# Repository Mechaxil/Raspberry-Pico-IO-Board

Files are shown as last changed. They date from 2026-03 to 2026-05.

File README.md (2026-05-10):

# Mechaxil Pico IO Board - [Documentation website](https://docs.mechaxil.com/docs/products/pico-io-board)

A clean, minimal Raspberry Pi Pico-compatible breakout board designed for easy access to all GPIO pins.

<p align="center">
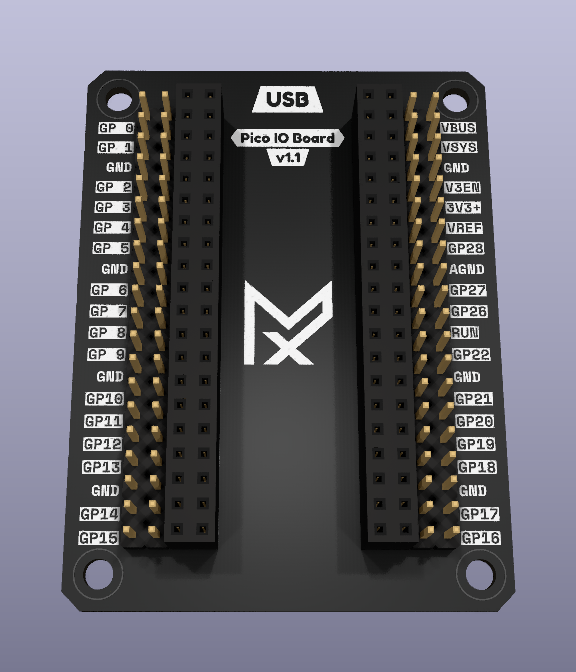
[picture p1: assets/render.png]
Render
  
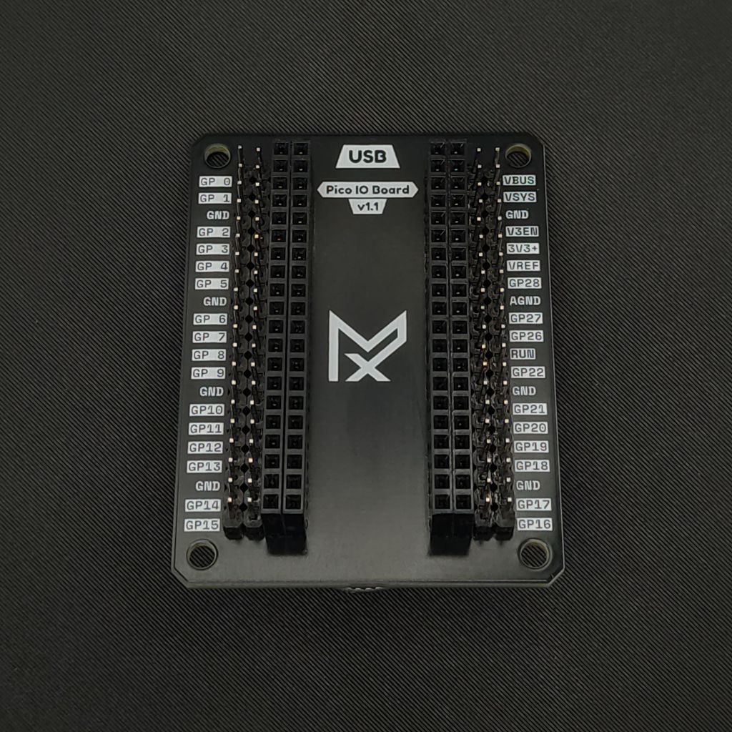
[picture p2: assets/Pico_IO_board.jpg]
Real
  
</p>

## Overview

The Mechaxil Pico IO Board expands the Raspberry Pi Pico pins so it's easier to use for prototyping.

Designed with usability, readability, and clean aesthetics in mind.

Perfect for prototyping, education, embedded development, and quick testing setups.

This board is available for purchase via the Mechaxil webshop:
[Mechaxil Webshop](https://mechaxil.com/products/pico-io-board)

## Features

- Full GPIO breakout  
- Clearly labeled pinout on silkscreen  
- Single-row female header  
- Dual-row male headers  
- Clean minimal design  

## Use Cases

- Rapid prototyping  
- Educational electronics kits  
- Embedded system development  
- DIY projects  

## Hardware

- Compatible with Raspberry Pi Pico and Pico-compatible boards  
- Standard 2.54 mm header spacing  
- Compact form factor  

## OSHW & License

As of 2026 May 8th this project was certified by OSHWA
<p align="center">
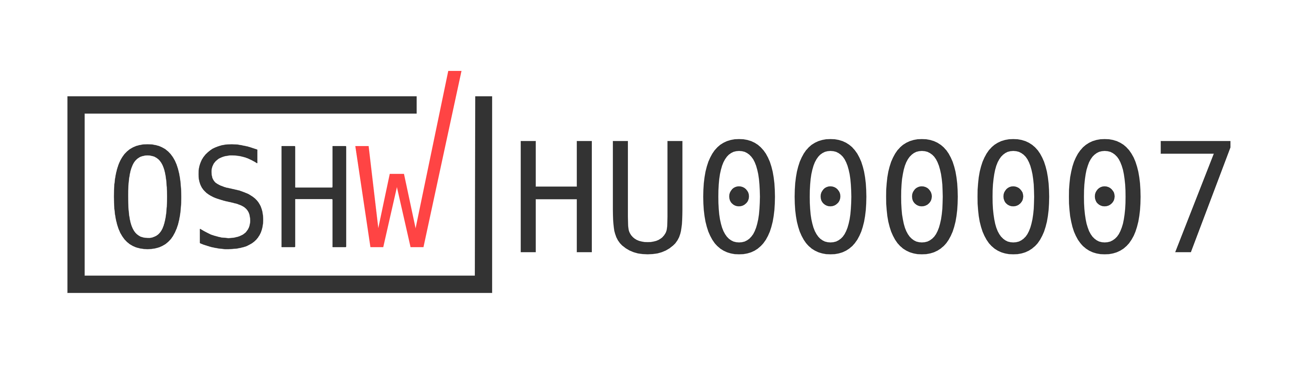
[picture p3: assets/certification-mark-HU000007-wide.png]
OSHW Mark
  
</p>

This project is licensed under the CERN Open Hardware Licence Version 2 - Weakly Reciprocal (CERN-OHL-W).

You are free to use, modify, manufacture, and sell.

Condition:
- Any modifications to the design must also be shared under the same license  

> [!IMPORTANT]
>
> ## Trademark & Branding Notice
>
> "Mechaxil" and the Mechaxil logo are trademarks of Mechaxil (Závoczki Attila e.v.).
> This license does not grant permission to use the Mechaxil name, logo, or branding for commercial or promotional purposes without prior written permission.
>
> If you manufacture, distribute, or sell this design (modified or unmodified):
>
> * You must remove the Mechaxil logo
> * You must remove any "Approved by Mechaxil" markings
> * You must not imply that your product is an official Mechaxil product
> * You must clearly state: "Original design by Mechaxil"
>
> This ensures transparency and avoids confusion between official Mechaxil products and third-party derivatives.

> [!IMPORTANT]
> ## Raspberry Pi Disclaimer
> "Raspberry Pi" is a trademark of the Raspberry Pi Foundation.
> This project is not affiliated with, endorsed by, or sponsored by the Raspberry Pi Foundation or Raspberry Pi Ltd.
> The term is used only for compatibility reference.

## Open Hardware

All design files are provided as schematics, PCB layouts, and production files.

Feel free to build, sell, improve, and share.

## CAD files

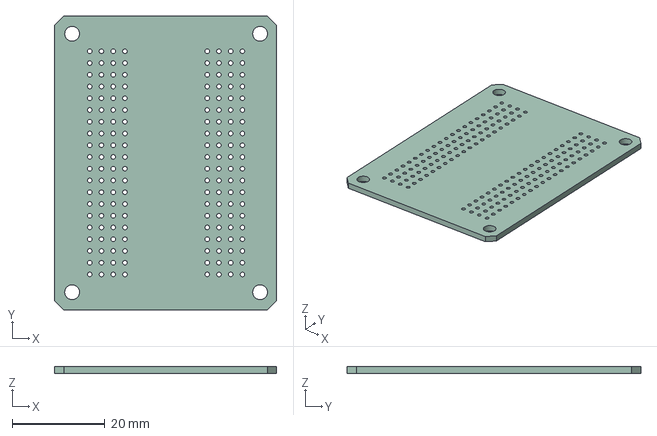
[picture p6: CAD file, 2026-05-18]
documentation/CAD/pico_io_board-no_component.step
48.0 x 63.5 x 1.51 mm

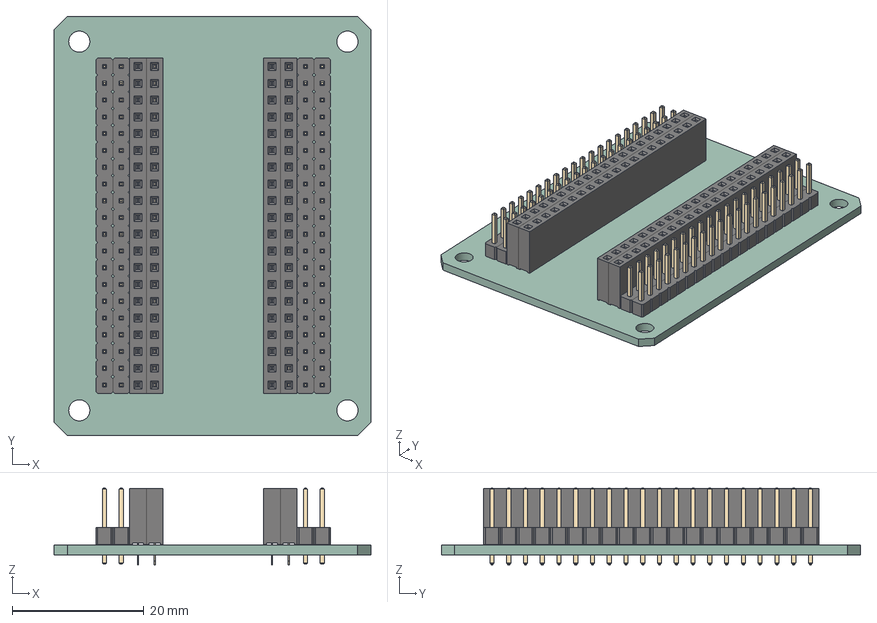
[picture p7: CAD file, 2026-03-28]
Raspberry_Pico_Breakout.step
48.0 x 63.5 x 11.6 mm
PinSocket_1x20_P2.54mm_Vertical x 4
PinHeader_1x20_P2.54mm_Vertical x 4
Raspberry_Pico_Breakout_PCB

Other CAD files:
documentation/CAD/pico_io_board-no_silkscreen.step

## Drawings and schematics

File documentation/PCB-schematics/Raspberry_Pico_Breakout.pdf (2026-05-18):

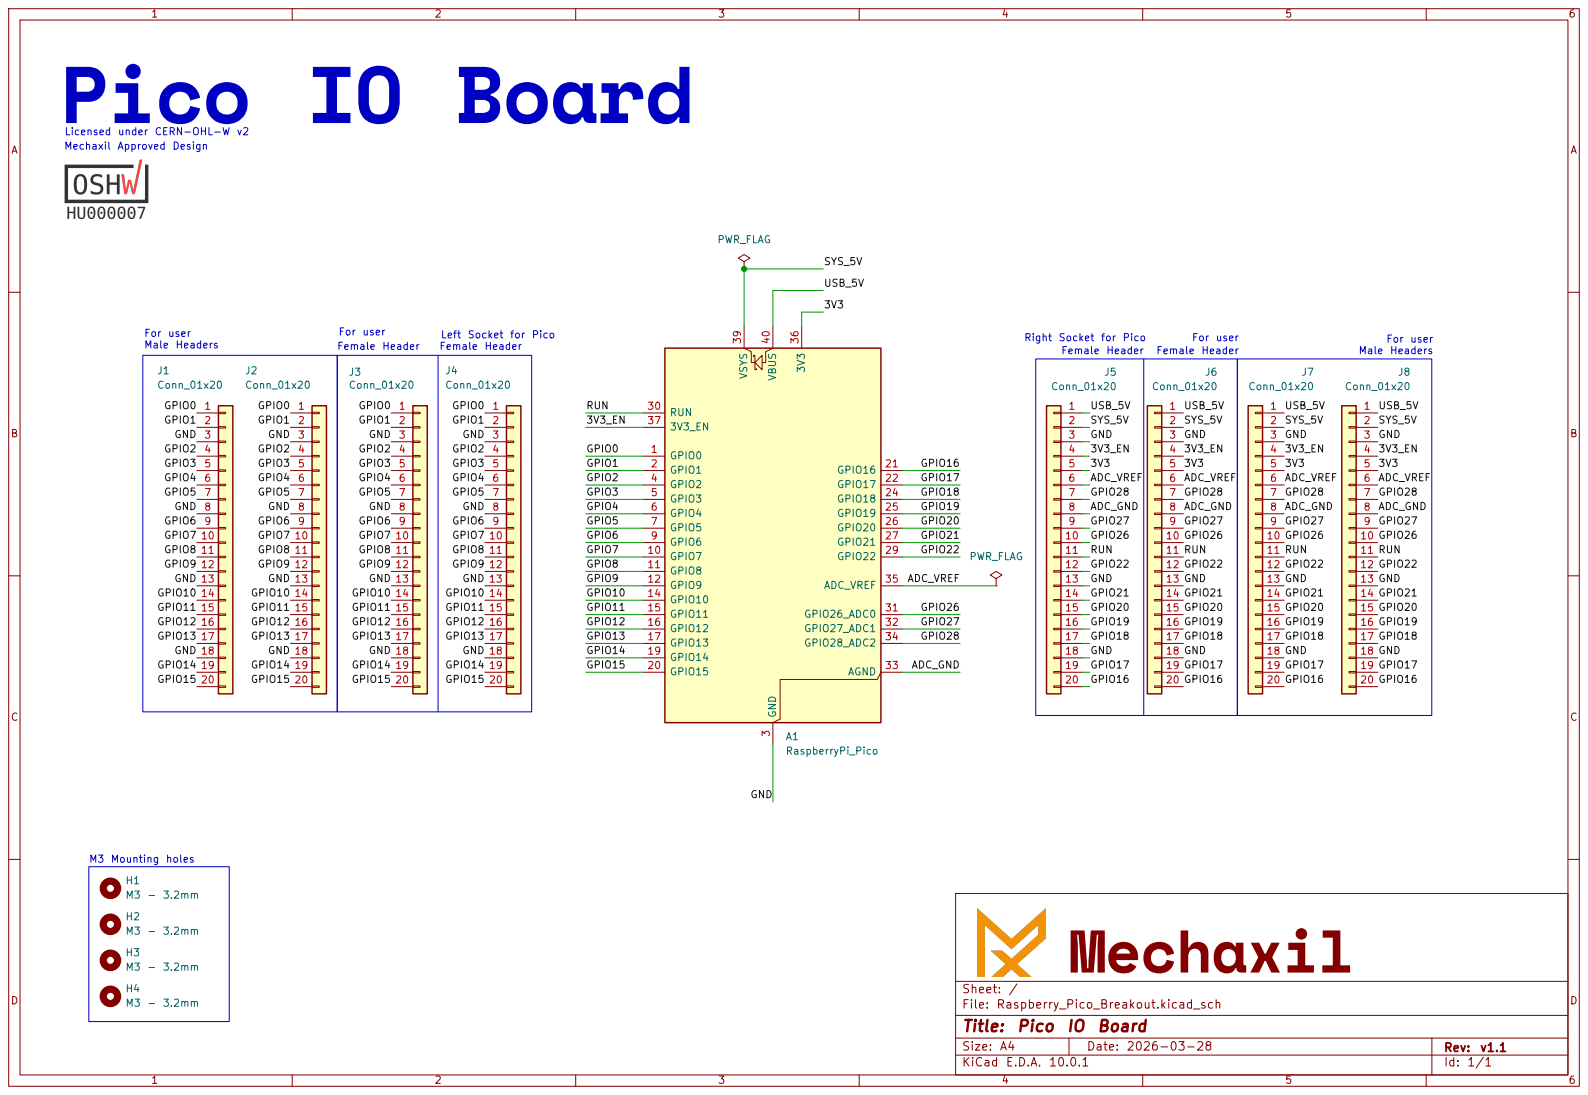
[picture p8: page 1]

Left Socket for Pico M3 Mounting holes

Sheet: /
File: Raspberry_Pico_Breakout.kicad_sch
Title: Pico IO Board

Size: A4 | Rev: v1.1
KiCad E.D.A. 10.0.1 | Id: 1/1

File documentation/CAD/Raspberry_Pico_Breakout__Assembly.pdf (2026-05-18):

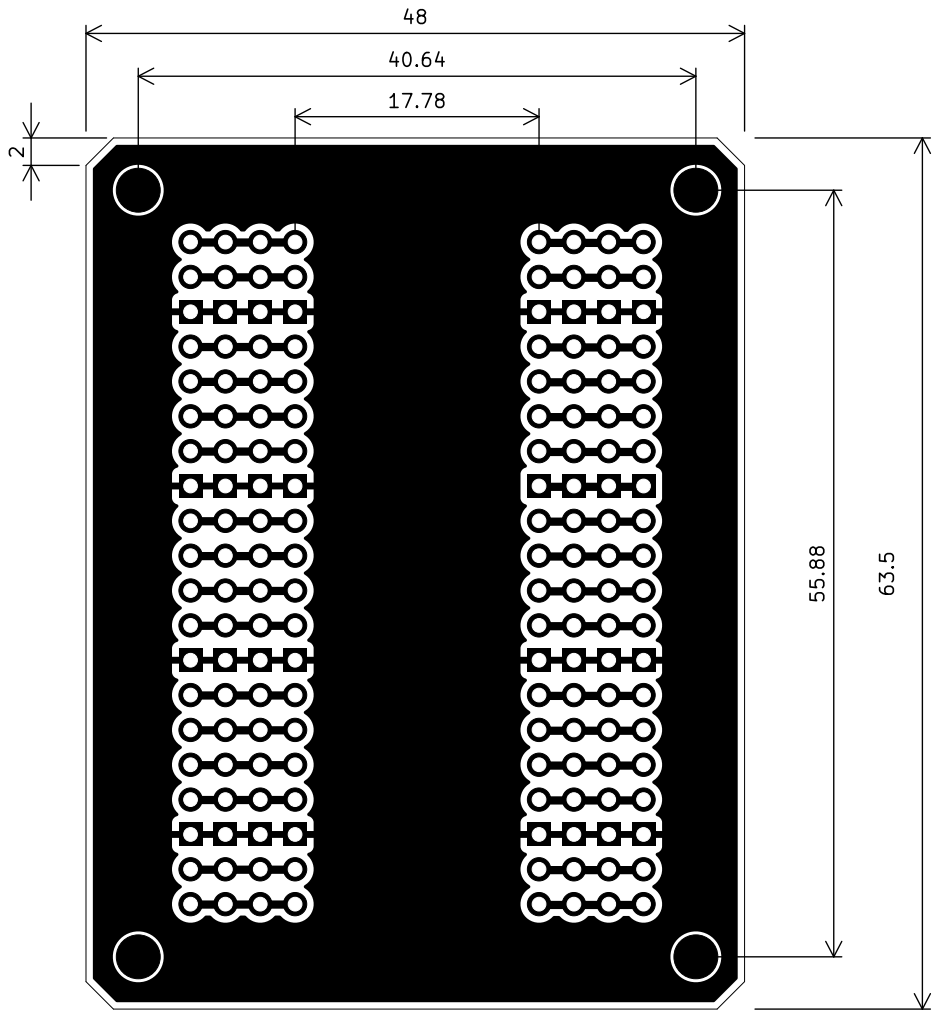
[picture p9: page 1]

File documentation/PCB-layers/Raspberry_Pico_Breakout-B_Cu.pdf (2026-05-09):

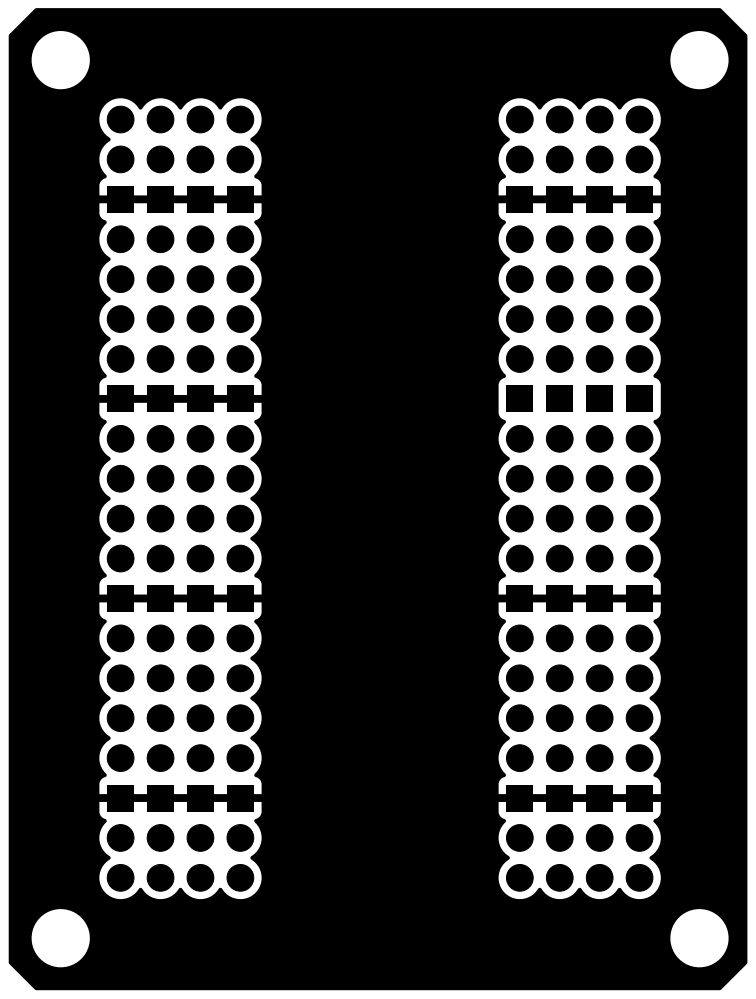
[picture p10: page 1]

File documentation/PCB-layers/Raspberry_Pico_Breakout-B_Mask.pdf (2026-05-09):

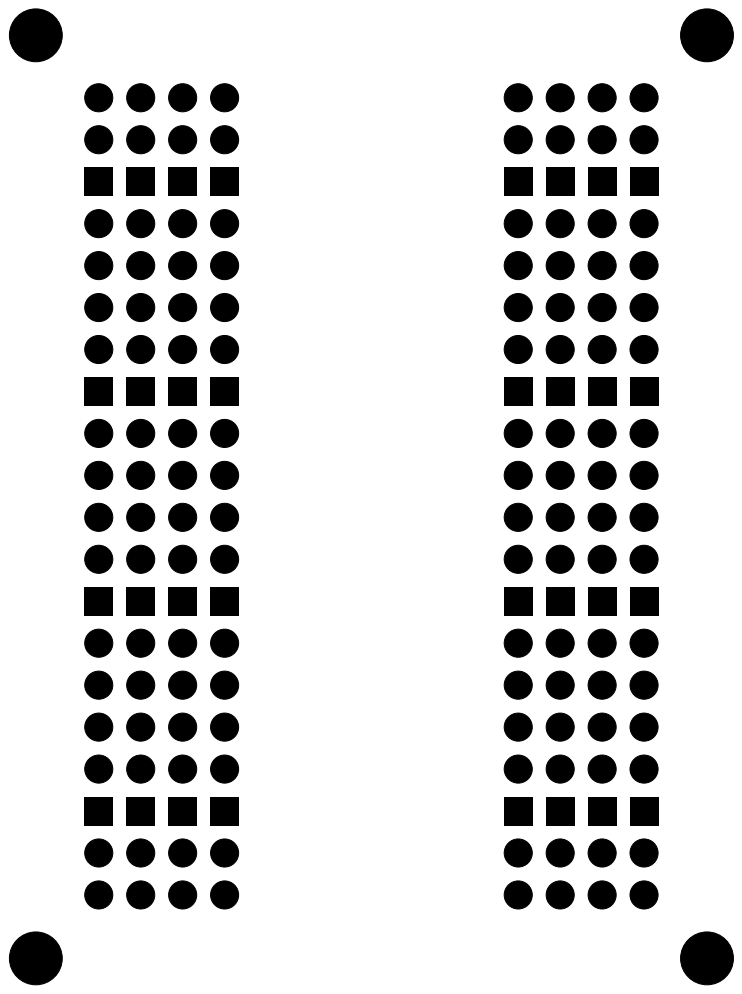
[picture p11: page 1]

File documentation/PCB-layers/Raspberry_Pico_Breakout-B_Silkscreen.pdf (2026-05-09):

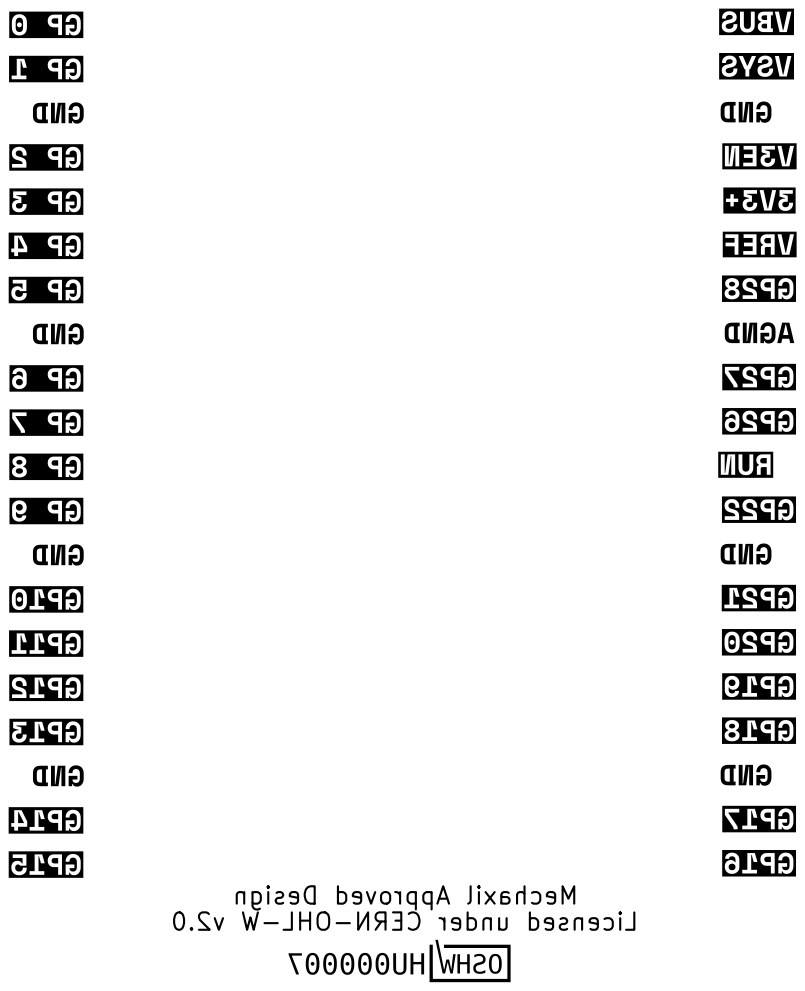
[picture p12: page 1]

v2.0 CERN-OHL-W under Licensed

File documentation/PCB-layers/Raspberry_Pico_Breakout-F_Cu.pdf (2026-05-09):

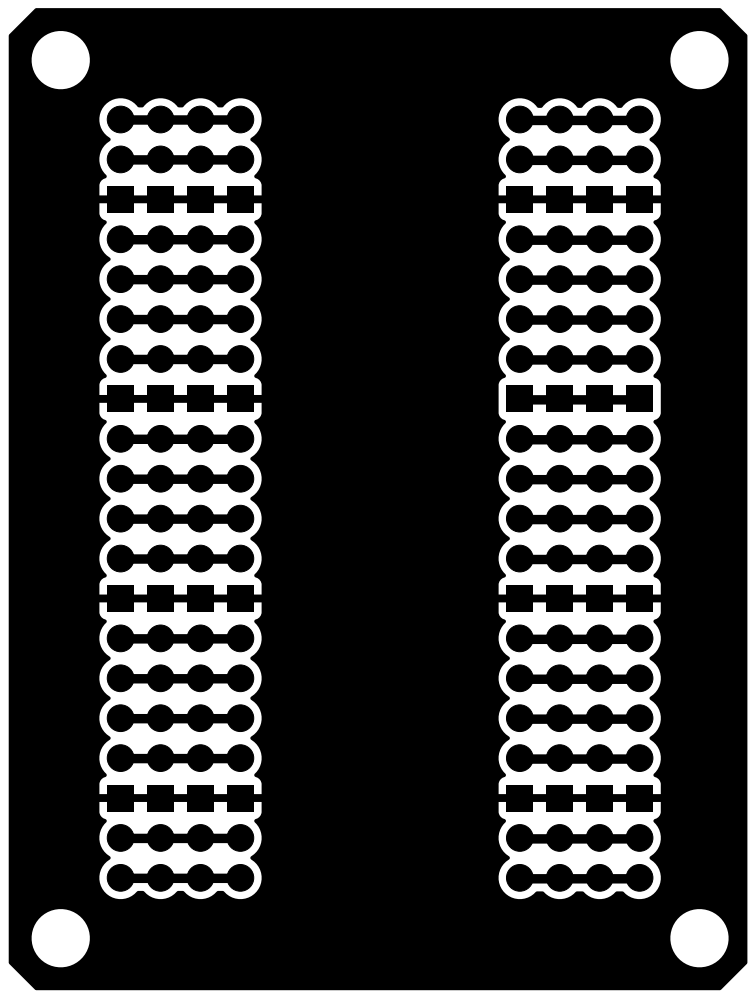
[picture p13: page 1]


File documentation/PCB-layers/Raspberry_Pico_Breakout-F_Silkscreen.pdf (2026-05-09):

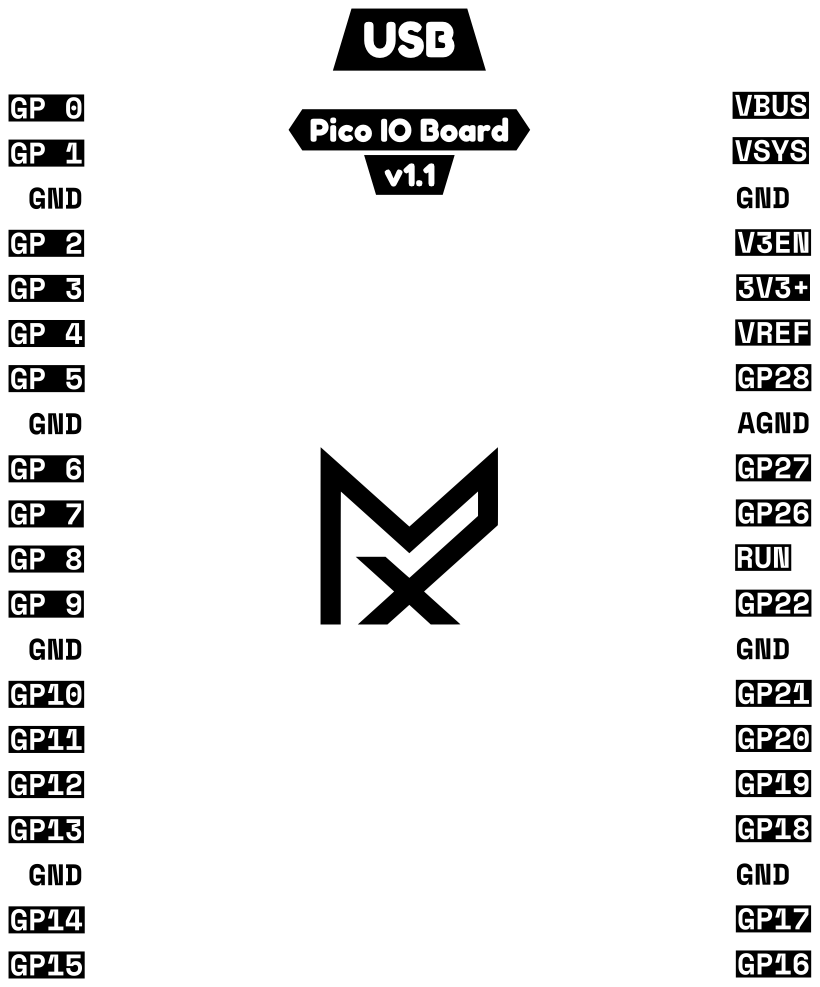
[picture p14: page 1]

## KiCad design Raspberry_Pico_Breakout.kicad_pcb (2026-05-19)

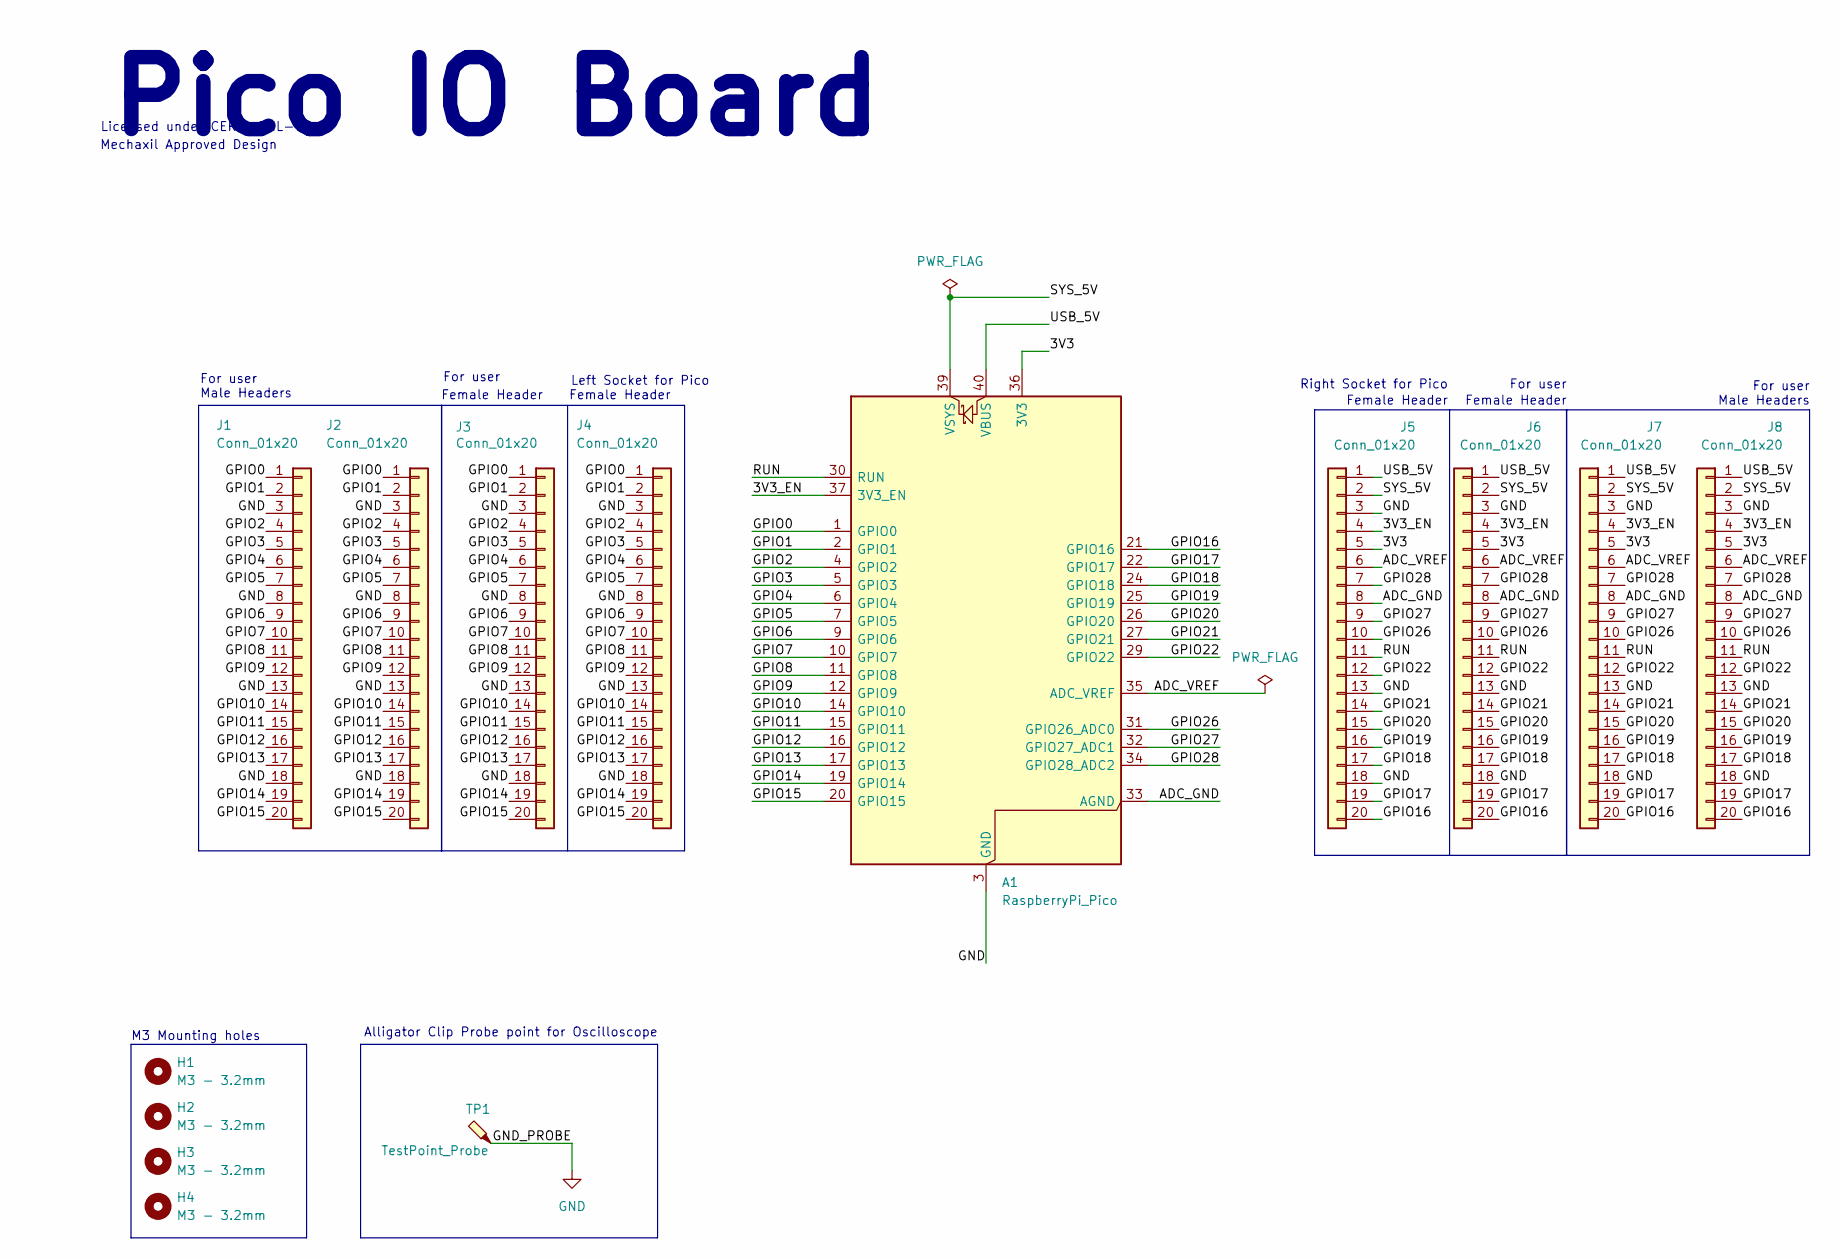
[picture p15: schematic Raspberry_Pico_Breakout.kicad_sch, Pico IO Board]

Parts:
A1: RaspberryPi_Pico; RaspberryPi_Pico_Common_Unspecified
H1, H2, H3, H4: M3 - 3.2mm; MountingHole_3.2mm_M3_ISO_4762
J1, J2, J7, J8: Conn_01x20; PinHeader_1x20_P2.54mm_Vertical_NoSilkscreen
J3, J4, J5, J6: Conn_01x20; PinSocket_1x20_P2.54mm_Vertical_NoSilkscreen
TP1: TestPoint_Probe; TestPoint_Loop_D2.50mm_Drill1.0mm_LowProfile

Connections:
/3V3: A1.36 (3V3), J5.5, J6.5, J7.5, J8.5
/3V3_EN: A1.37 (3V3_EN), J5.4, J6.4, J7.4, J8.4
/ADC_GND: A1.33 (AGND), J5.8, J6.8, J7.8, J8.8
/ADC_VREF: A1.35 (ADC_VREF), J5.6, J6.6, J7.6, J8.6
/GPIO0: A1.1 (GPIO0), J1.1, J2.1, J3.1, J4.1
/GPIO1: A1.2 (GPIO1), J1.2, J2.2, J3.2, J4.2
/GPIO2: A1.4 (GPIO2), J1.4, J2.4, J3.4, J4.4
/GPIO3: A1.5 (GPIO3), J1.5, J2.5, J3.5, J4.5
/GPIO4: A1.6 (GPIO4), J1.6, J2.6, J3.6, J4.6
/GPIO5: A1.7 (GPIO5), J1.7, J2.7, J3.7, J4.7
/GPIO6: A1.9 (GPIO6), J1.9, J2.9, J3.9, J4.9
/GPIO7: A1.10 (GPIO7), J1.10, J2.10, J3.10, J4.10
/GPIO8: A1.11 (GPIO8), J1.11, J2.11, J3.11, J4.11
/GPIO9: A1.12 (GPIO9), J1.12, J2.12, J3.12, J4.12
/GPIO10: A1.14 (GPIO10), J1.14, J2.14, J3.14, J4.14
/GPIO11: A1.15 (GPIO11), J1.15, J2.15, J3.15, J4.15
/GPIO12: A1.16 (GPIO12), J1.16, J2.16, J3.16, J4.16
/GPIO13: A1.17 (GPIO13), J1.17, J2.17, J3.17, J4.17
/GPIO14: A1.19 (GPIO14), J1.19, J2.19, J3.19, J4.19
/GPIO15: A1.20 (GPIO15), J1.20, J2.20, J3.20, J4.20
/GPIO16: A1.21 (GPIO16), J5.20, J6.20, J7.20, J8.20
/GPIO17: A1.22 (GPIO17), J5.19, J6.19, J7.19, J8.19
/GPIO18: A1.24 (GPIO18), J5.17, J6.17, J7.17, J8.17
/GPIO19: A1.25 (GPIO19), J5.16, J6.16, J7.16, J8.16
/GPIO20: A1.26 (GPIO20), J5.15, J6.15, J7.15, J8.15
/GPIO21: A1.27 (GPIO21), J5.14, J6.14, J7.14, J8.14
/GPIO22: A1.29 (GPIO22), J5.12, J6.12, J7.12, J8.12
/GPIO26: A1.31 (GPIO26_ADC0), J5.10, J6.10, J7.10, J8.10
/GPIO27: A1.32 (GPIO27_ADC1), J5.9, J6.9, J7.9, J8.9
/GPIO28: A1.34 (GPIO28_ADC2), J5.7, J6.7, J7.7, J8.7
/RUN: A1.30 (RUN), J5.11, J6.11, J7.11, J8.11
/SYS_5V: A1.39 (VSYS), J5.2, J6.2, J7.2, J8.2
/USB_5V: A1.40 (VBUS), J5.1, J6.1, J7.1, J8.1
GND: A1.3 (GND), A1.8 (GND), A1.13 (GND), A1.18 (GND), A1.23 (GND), A1.28 (GND), A1.38 (GND), J1.3, J1.8, J1.13, J1.18, J2.3, J2.8, J2.13, J2.18, J3.3, J3.8, J3.13, J3.18, J4.3, J4.8, J4.13, J4.18, J5.3, J5.13, J5.18, J6.3, J6.13, J6.18, J7.3, J7.13, J7.18, J8.3, J8.13, J8.18, TP1.1 (1_1)

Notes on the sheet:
Licensed under CERN-OHL-W v2
Pico IO Board
Left Socket for Pico
Mechaxil Approved Design
Female Header
Male Headers
For user
M3 Mounting holes
Right Socket for Pico
Alligator Clip Probe point for Oscilloscope

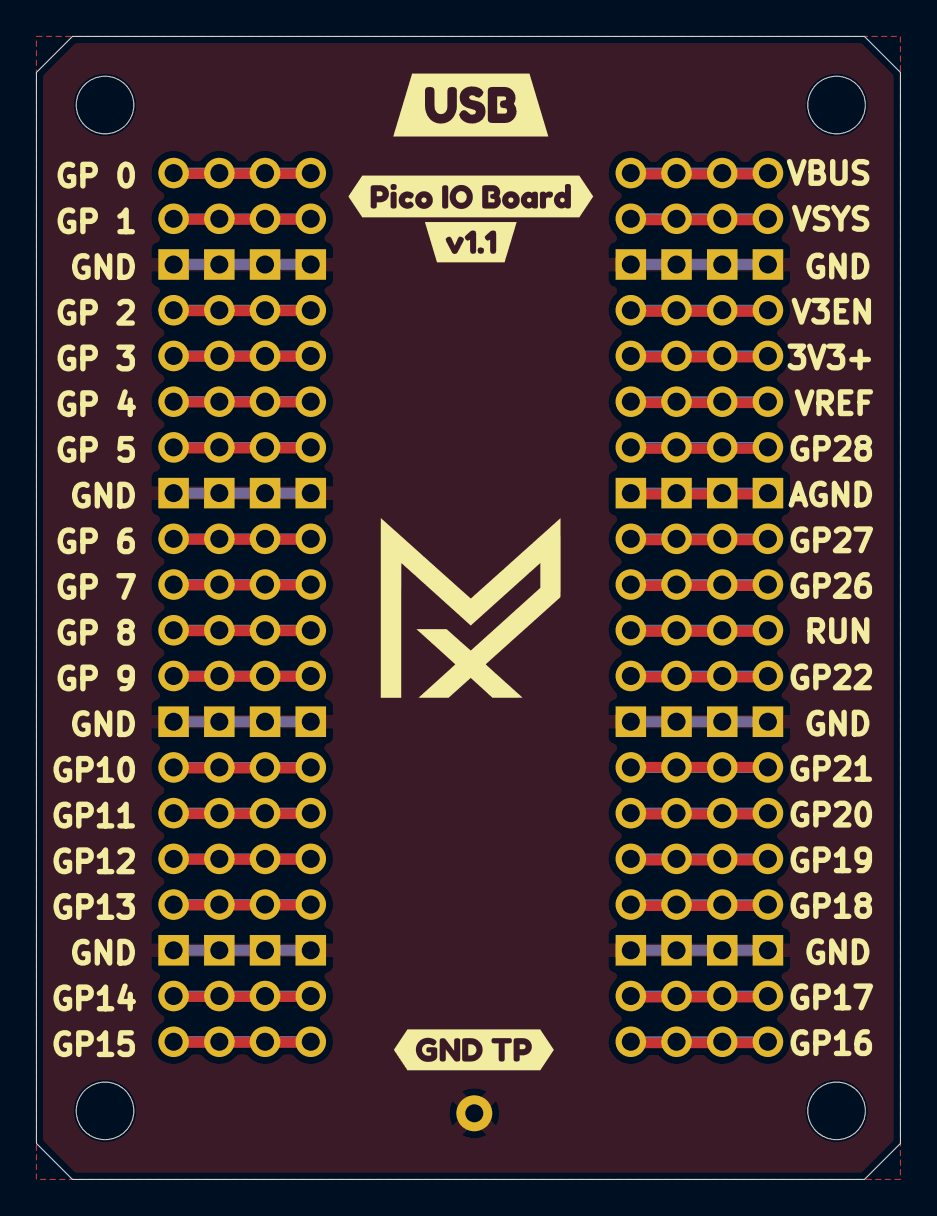
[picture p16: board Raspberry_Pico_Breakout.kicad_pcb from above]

Board: 2 copper layers, 48.0 x 63.5 mm, 17 parts (0 on the bottom side), 34 nets.

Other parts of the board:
kibuzzard-6A0C12EA: G***; kibuzzard-6A0C12EA
kibuzzard-6A0C1342: G***; kibuzzard-6A0C1342
kibuzzard-694057F1: G***; kibuzzard-694057F1
kibuzzard-6940576A: G***; kibuzzard-6940576A

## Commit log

2026-05-01 doc: updated part documentation, schematics readability
    [Raspberry_Pico_Breakout.kicad_sch]
2026-05-03 doc: updated on schematic and PCB added license and design text
    [Raspberry_Pico_Breakout.kicad_pcb, Raspberry_Pico_Breakout.kicad_sch]
2026-05-09 major: upgrade to KiCAD 10.0 and OSHW License
    [Raspberry_Pico_Breakout.kicad_pcb, Raspberry_Pico_Breakout.kicad_sch]
2026-05-18 Doc: update layers and sch, change font to space mono, export step
    [Raspberry_Pico_Breakout.kicad_pcb, Raspberry_Pico_Breakout.kicad_sch, pico_io_board-no_component.step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]
2026-05-19 feat: Probe GND pad for easy oscilloscope attachment
    [Raspberry_Pico_Breakout.kicad_pcb, Raspberry_Pico_Breakout.kicad_sch]

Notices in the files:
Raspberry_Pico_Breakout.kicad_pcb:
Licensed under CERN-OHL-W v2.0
